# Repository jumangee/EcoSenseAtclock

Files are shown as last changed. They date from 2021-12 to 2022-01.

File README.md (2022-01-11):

# EcoSense@clock
Tiny, simple and cheap indoor air quality controller with meteo station, clocks, OLED and web-reporting using Arduino Nano and ESP-01S

Photos and more description at [Hackaday.io](https://hackaday.io/project/183222-ecosenseclock)

**Features list**
- 3 monitored environment indicators
- 7 sensors for assessment of gas impurities in air
- Web reporting (ThingSpeak API, 2 channels)
- On-screen warnings
- Real-time clock
- .96" SSD1306 OLED display
- 5V and 3.3V power adapter
- Intelligent power management (no more than .4A current)
- Modular, event-driven architecture (using [Processy Firmware Framework](https://github.com/jumangee/arduino-nano-taskman))
- Small memoty consuption and footprint
- Easy support and upgrade

**Intelligent power management scheme**

- Constantly active devices (total: ~150mA):
  - Arduino Nano: ~20mA
  - DS3211: <1mA
  - BME280: 1mA
  - ESP-01: max 120mA (3.3V)
  - OLED: max 15mA
  - MH-Z19B: max 150mA    // CO2 sensor
  - Sensor button // switch through on-screen warnings list
- Periodically powered:
  - Group 1
    - CJMCU-1100: max 190mA    // Formaldehyde Benzene Toluene
    - MQ-136: max 150mA        // Hydrogen Sulfide
  - Group 2
    - MQ-135: max 150mA        // Air Quality (CO, Ammonia, Benzene, Alcohol, smoke)
    - MQ-4: max 150mA            // methane
  - Group 3
    - MQ-7: max 150mA         // CO sensor
    - PPD-42NS: max 90mA      // particle sensor, currently measures only PM2.5

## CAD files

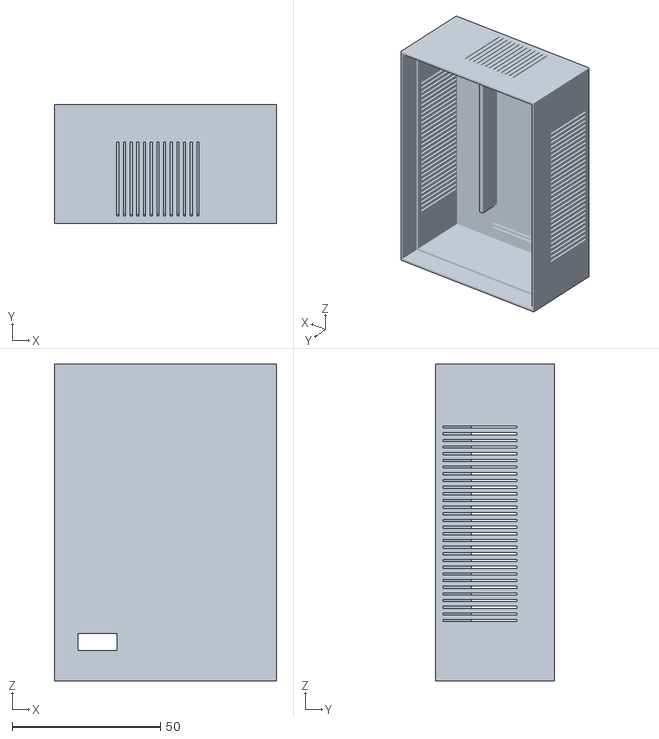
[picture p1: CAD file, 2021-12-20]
_enclosure/v1/box_part2.stl
74.9 x 40.0 x 106.9

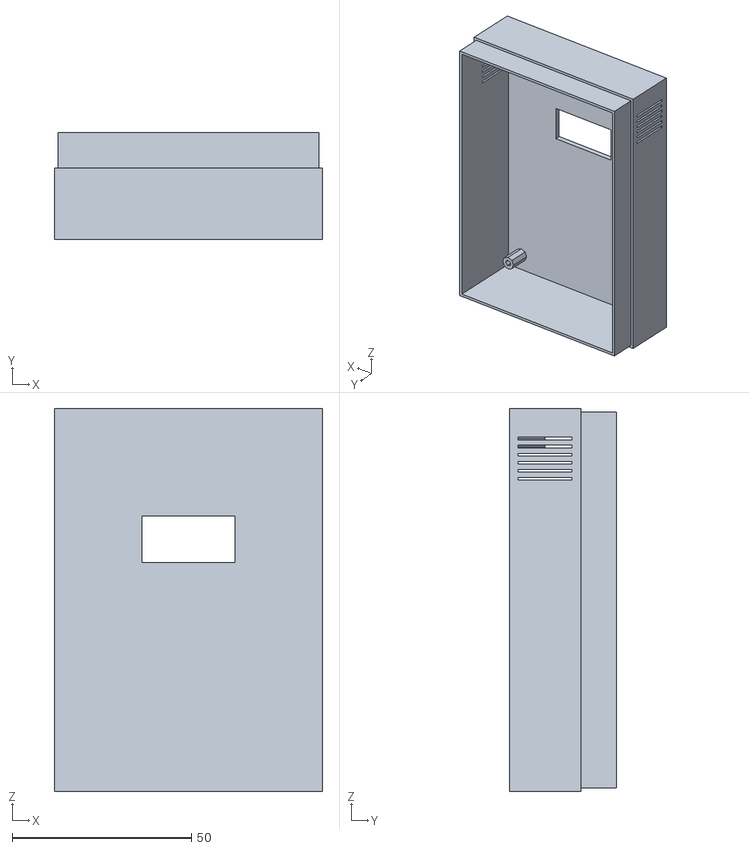
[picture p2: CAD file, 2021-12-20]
_enclosure/v1/box_part1.stl
74.9 x 30.0 x 106.9

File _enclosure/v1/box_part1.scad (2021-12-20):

// EcoSense@clock: box, part1 (front)

//color("white")

box_thicknes = 2;
panel_width = 64.897;
panel_height = 96.901;
mount_holes_width = 58.547;
mount_holes_height = 90.170;
mount_hole_diameter = 2.5;
mount_hole_z = 8;

display_width = 26;
display_height = 13;
display_pos_h = 25;

vent_hole_height = 0.75;
vent_hole_width = 15;
vent_hole_pos_h = 20;
vent_hole_count = 5;

box_deep = 20;
box2panel_size = box_thicknes + 3;
box_width = panel_width + 2 * box2panel_size;
box_height = panel_height + 2 * box2panel_size;

echo(box2panel_size=box2panel_size);
echo(box_width=box_width);
echo(box_height=box_height);

mount_pos_w = (panel_width - mount_holes_width) / 2;
mount_pos_h = (panel_height - mount_holes_height) / 2;
echo(mount_pos_w=mount_pos_w);

translate([0,0,0]) {
    difference() {
        union() {
            cube([box_width, box_deep, box_height]);
            translate([box_thicknes/2,box_deep,box_thicknes/2]) {
                cube([box_width-box_thicknes, 10, box_height-box_thicknes]);
            }
        }
        
        translate([
            (box2panel_size+
            panel_width/2-
            display_width/2)
        ,
            -1
        ,
            box2panel_size + panel_height - display_pos_h - display_height
        ]) 
            cube([display_width, 50, display_height]);
        
        translate([box_thicknes,box_thicknes,box_thicknes])
            cube([(box_width-box_thicknes*2), box_deep*2, (box_height-box_thicknes*2)]);
        
    // vent holes
    pos_h = box_height - vent_hole_pos_h;
        
    for(h = [
        pos_h+((vent_hole_height + vent_hole_height*2)*vent_hole_count):
        -(vent_hole_height + vent_hole_height*2):
        pos_h
        ]) {
        
        
        translate([
                -1
            ,
                box_deep/2 -            vent_hole_width/2
            ,
                h
            ]) 
                cube([box_width*2, vent_hole_width, vent_hole_height]);
    }
    
    /*vent_hole_height = 0.5;
vent_hole_width = 20;
vent_hole_pos_h = 20;
vent_hole_count = 5;*/

    }
}


rotate([90,0,0]) {
    translate([mount_pos_w + box2panel_size,mount_pos_h+box2panel_size,-(box_thicknes+mount_hole_z)])
        difference() {
            cylinder(h=(mount_hole_z),r=mount_hole_diameter);
            translate([0,0,-1])
                cylinder(h=(box_deep / 2),r=(mount_hole_diameter/2));
        }

    translate([mount_pos_w + box2panel_size + mount_holes_width,mount_pos_h+box2panel_size,-(box_thicknes+mount_hole_z)])
        difference() {
            cylinder(h=(mount_hole_z),r=mount_hole_diameter);
            translate([0,0,-1])
                cylinder(h=(box_deep / 2),r=(mount_hole_diameter/2));
        }
        
    translate([mount_pos_w + box2panel_size + mount_holes_width,mount_pos_h+box2panel_size + mount_holes_height,-(box_thicknes+mount_hole_z)])
        difference() {
            cylinder(h=(mount_hole_z),r=mount_hole_diameter);
            translate([0,0,-1])
                cylinder(h=(box_deep / 2),r=(mount_hole_diameter/2));
        }
        
    translate([mount_pos_w + box2panel_size,mount_pos_h+box2panel_size + mount_holes_height,-(box_thicknes+mount_hole_z)])
        difference() {
            cylinder(h=(mount_hole_z),r=mount_hole_diameter);
            translate([0,0,-1])
                cylinder(h=(box_deep / 2),r=(mount_hole_diameter/2));
        }
}


echo(version=version());

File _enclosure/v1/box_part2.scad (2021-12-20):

// EcoSense@clock: box, part2 (back)

//color("white")

box_thicknes = 2;
panel_width = 64.897;
panel_height = 96.901;
mount_holes_width = 58.547;
mount_holes_height = 90.170;
mount_hole_diameter = 2.5;
mount_hole_z = 8;

vent_hole_height = 0.75;
vent_hole_width = 25;
vent_hole_pos_h = 20;
vent_hole_count = 25;

box_deep = 30;
box2panel_size = box_thicknes + 3;
box_width = panel_width + 2 * box2panel_size;
box_height = panel_height + 2 * box2panel_size;

mount_pos_w = (panel_width - mount_holes_width) / 2;
mount_pos_h = (panel_height - mount_holes_height) / 2;
echo(mount_pos_w=mount_pos_w);

translate([0,0,0]) {
    difference() {
        
        cube([box_width, box_deep, box_height]);
       
        translate([box_thicknes,box_thicknes,box_thicknes])
            cube([(box_width-box_thicknes*2), box_deep, (box_height-box_thicknes*2)]);
        
    // vent holes
    pos_h = box_height - vent_hole_pos_h;
   echo(pos_h=pos_h);

   echo(s=box_height-((vent_hole_height + vent_hole_height*2)*vent_hole_count));
        
    for(h = [
        vent_hole_pos_h:
        (vent_hole_height + vent_hole_height*2):
        box_height - vent_hole_pos_h
        ]) {
        
        echo(h=h);
        
        translate([
                -1
            ,
                box_deep/2 -            vent_hole_width/2
            ,
                h
            ]) 
                cube([box_width*2, vent_hole_width, vent_hole_height]);
        echo(pos_h=pos_h);
    }
    
    for(h = [
        vent_hole_pos_h+box_thicknes:
        (vent_hole_height + vent_hole_height*2):
        box_width - vent_hole_pos_h-4
        ]) {
        
        translate([
                h-1
            ,
                box_deep/2 -            vent_hole_width/2
            ,
                box_height-box_thicknes*2
            ]) 
                cube([vent_hole_height, vent_hole_width, box_thicknes*3]);
    }
    
        // usb
    translate([
        6 + box_thicknes,
        -1,
        10.3
        ]) {
        cube([13.1, box_thicknes*3, 5.7]);
        }
    
    }
}

difference() {
    translate([0,box_deep,0]) {
        cube([box_width, 10, box_height]);
    }
    translate([box_thicknes/2,box_deep-1,box_thicknes/2]) {
        cube([box_width-box_thicknes, 12, box_height-box_thicknes]);
    }
}

translate([
box_thicknes+vent_hole_pos_h - box_thicknes*2-.5,
box_thicknes,
vent_hole_pos_h
]) {
cube([box_thicknes, box_deep/3, box_height - vent_hole_pos_h]);

}

translate([
box_thicknes+vent_hole_pos_h - box_thicknes*2 + 30+ box_thicknes + 0.5,
box_thicknes,
vent_hole_pos_h
]) {
cube([box_thicknes, box_deep/3, box_height - vent_hole_pos_h]);

}

// mb102 rails
translate([
box_thicknes,
box_thicknes,
box_thicknes + 7// 9.3 - 1.3 - box_thicknes/2
]) {
cube([1, 28, 1]);
cube([50, 1, 1]);
}

translate([
box_thicknes,
box_thicknes,
box_thicknes + 5  //9.3 - 1.3 - box_thicknes/2 - 1.2 - box_thicknes/2
]) {
cube([1, 28, 1]);
cube([50, 1, 1]);
}


echo(version=version());

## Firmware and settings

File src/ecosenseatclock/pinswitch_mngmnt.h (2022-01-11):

#ifndef _PINSWITCHMNGR_H
#define _PINSWITCHMNGR_H

    #include <Arduino.h>
    #include "processy_cfg.h"

    #define USEDPIN_NONE 255

    class PinSwitchManager {
        protected:
            PinSwitchManager(byte *pins, byte keysCnt) {
                this->keyPins = pins;
                this->pinsCnt = keysCnt;
                this->currentPin = USEDPIN_NONE;
                this->useStarted = 0;

                for (byte i = 0; i < this->pinsCnt; i++) {
                    pinMode(this->keyPins[i], OUTPUT);
                }

                this->closeAll();
            }

        public:
            /**
             * Request to use pin (start transaction)
             * 0 - fail, >0 - success (open time)
             */
            //@implement
            uint32_t requestPin(byte targetPin) {
                if (currentPin == USEDPIN_NONE) {
                    this->usePin(targetPin);
                    return this->useStarted;
                }
                return 0;
            }

            /**
             * Turn off previosly opened pin by key from requestPin, or forcibly off any pin
             * (force off: key = 0)
             * true - ok, false - nothing changed!
             */
            //@implement
            bool releasePin(uint32_t & key) {
                if (key == 0 || key == this->useStarted) {
                    this->closeAll();   // fully off
                    return true;
                }
                return false; // nothing changed!
            }

        protected:
            byte                *keyPins;  // arr
            byte                pinsCnt;   // cnt
            uint32_t            useStarted;
            byte                currentPin;

            //@implement
            void closeAll() {
                for (byte i = 0; i < this->pinsCnt; i++) {
                    byte pin = this->keyPins[i];
                    digitalWrite(pin, LOW);
                }
                this->useStarted = 0;
                this->currentPin = USEDPIN_NONE;
            }

            //@implement
            virtual void usePin(byte num) {
                // fully off, then make
                this->closeAll();

                for (byte i = 0; i < this->pinsCnt; i++) {
                    byte pin = this->keyPins[i];
                    if (num == pin) {
                        digitalWrite(num, HIGH);
                        this->currentPin = num;
                        this->useStarted = millis();
                    }
                }
            }
    };

#endif

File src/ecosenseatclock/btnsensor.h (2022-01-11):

/**
 * Button sensor BASE
 */

#ifndef _BTNSENSOR_BASE_H
#define _BTNSENSOR_BASE_H

#include <Arduino.h>
#include "ecosense_messages.h"

#define BTNCLICK_TIME 300
#define BTNHOLD_TIME 5000

class ButtonSensor {
	private:
        bool        lastBtnState = false;
        uint32_t    pressDn = 0;
        uint32_t    lastClick = 0;
        byte        btnPin;
	public:
        ButtonSensor(byte pin) {
            this->btnPin = pin;
		}

        //@implement
        //@include "ecosense_messages.h"
		ButtonClickMessage* update() {
            bool isPressed = ( ((float)analogRead( btnPin )) * (5.0 / 1023.0) ) > 3.5;
            uint32_t curTime = millis();
            if (lastBtnState == true && isPressed == false) {
                uint32_t pressed = (curTime - pressDn);
                #if BTN_SUPPORT_HOLD == 1
                if ( pressed > BTNHOLD_TIME ) {
                    // hold
                    return this->getBtnEvent( BUTTON_EVENT::HOLD );
                } else {
                #endif
                    #if BTN_SUPPORT_DBLCLCK == 1
                    // click
                    if (lastClick > 0 && (curTime - lastClick < BTNCLICK_TIME)) { // DOUBLE CLICK
                        lastClick = 0;
                        return this->getBtnEvent( BUTTON_EVENT::DBLCLICK );
                    } else {
                    #endif
                        // remember this tap!)
                        lastClick = curTime;
                        lastBtnState = false;
                    #if BTN_SUPPORT_DBLCLCK == 1
                    }
                    #endif
                #if BTN_SUPPORT_HOLD == 1
                }
                #endif
            } else if (lastBtnState == false) {
                if (isPressed == true) {
                    pressDn = curTime;
                    lastBtnState = true;
                } else if (lastClick > 0 && (millis() - lastClick < BTNCLICK_TIME)) {
                    // react on single click
                    return this->getBtnEvent( BUTTON_EVENT::CLICK );
                }
            }
            return NULL;
		}

        //@implement
        //@include "ecosense_messages.h"
        ButtonClickMessage* getBtnEvent(BUTTON_EVENT type) {
            lastClick = 0;
            pressDn = 0;
            lastBtnState = false;

            return new ButtonClickMessage( btnPin, type );
        }
};

#endif

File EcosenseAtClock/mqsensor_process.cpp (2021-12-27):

#include "mqsensor_process.h"
#include "ecosense_cfg.h"
#include "ecosense_messages.h"

MQSensorProcess::MQSensorProcess(byte channel, IProcessMessage* msg) : SimpleSensorProcess(msg){
	this->channel = channel;
}

uint16_t MQSensorProcess::getInstantValue() {
            return analogRead( ADCMUX_SIGNAL_PIN );
        }

void MQSensorProcess::update(unsigned long ms) {
	//uint32_t ticket = ADCMuxManagement::get()->requestChannel(this->channel);	// ADC MUX PIN!
	if (this->getChannel(this->channel)) {
		bool done = this->readingsDone(MQ_READINGS_PER_RESULT);
		//ADCMuxManagement::get()->release(ticket);
		this->freeChannel();
		if (done) {
			TRACELNF("MQSensorProcess:done!")
			IProcessMessage* result = this->getResultMsg();
			if (result) {
				this->sendMessage(result);
				this->sendMessage(new TaskDoneMessage(this));
			}
			this->pause();
			return;
		}
	}
	TRACEF("MQSensor: ")
	TRACE(this->getId())
	TRACEF(" updated: ")
	TRACELN(getValue())
	this->pause(MQ_READING_TIMEOUT);
}

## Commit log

2021-01-21 rebranding, process "stop" fix
    [ecosense_cfg.h, ecosenseatclock.cpp, mqsensor_process.cpp]
2021-01-23 power management and processy bugfixes
    [mqsensor_process.cpp]
2021-01-24 pwr management fix, adc mux management fix, optimizations
    [adcmux_mngmnt.cpp, mqsensor_process.cpp, pinswitch_mngmnt.h]
2021-01-26 new sensor processes, cfg
2021-12-20 code reorganization, finishing touches(?), processy update
    [box_part1.scad, box_part1.stl, box_part2.scad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]
2021-12-21 time display and stability fixes
    [display_process.h, ecosense_cfg.h]
2021-12-23 stability issues, not fixed :(
    [feeds.csv]
2021-12-24 softwareserial optimization and bugfixes
    [ecosense_cfg.h, ecosenseatclock.cpp]
2022-01-05 button now more universal to multiusable
